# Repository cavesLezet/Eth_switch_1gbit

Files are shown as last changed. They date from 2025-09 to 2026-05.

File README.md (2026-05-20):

# Eth_switch_1gbit
на что смотрел:<br>
https://en.eeworld.com.cn/Reference_Designs/detail/76488<br>
https://lceda.cn/editor#id=103e28de87c54869b766a7df2fd9f07f<br>
https://github.com/Starrynightzyq/GE-Switch<br>
https://static.chipdip.ru/lib/518/DOC041518607.pdf<br>
https://oshwlab.com/hawaii0707/rtl8367rb-vb-cg<br>

инфа про светодиоды<br>
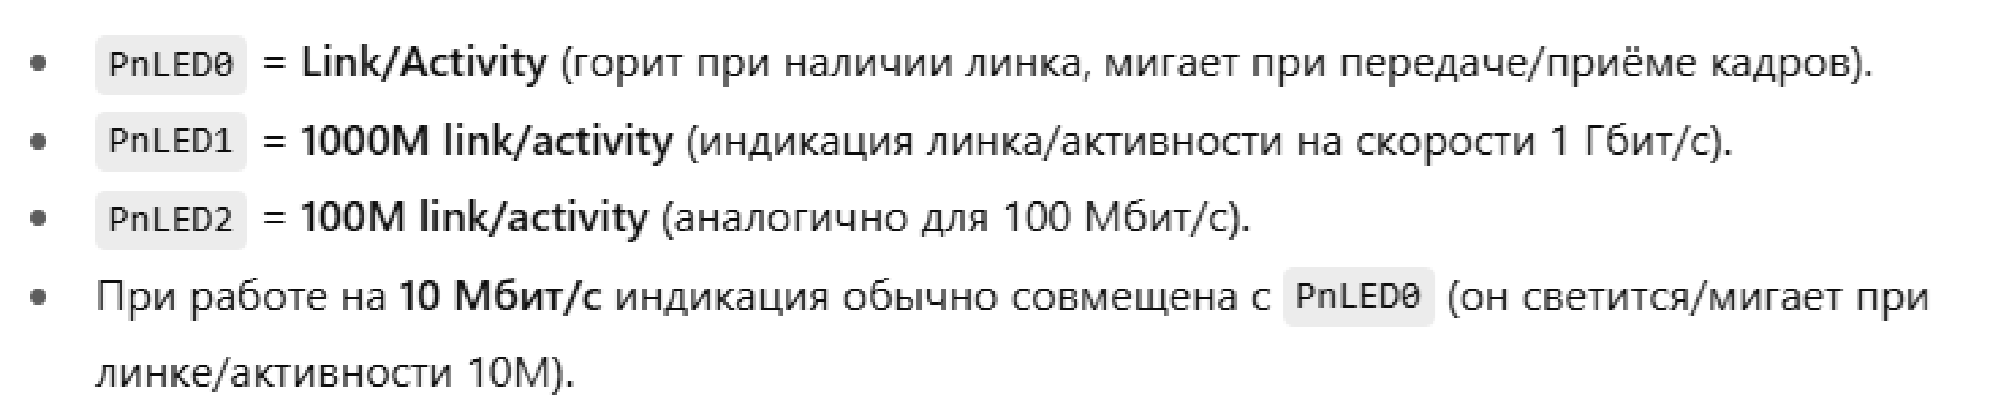
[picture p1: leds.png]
leds
<br>
[коммит с релизной докой](https://github.com/cavesLezet/Eth_switch_1gbit/commit/48998cd221b385a8897a50ce54fa7af490ef88a7)

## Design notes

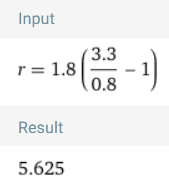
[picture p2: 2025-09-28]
Точечный рисунок (6).bmp

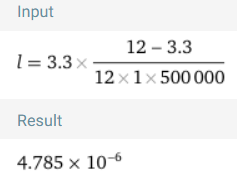
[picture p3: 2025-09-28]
Точечный рисунок (4).bmp

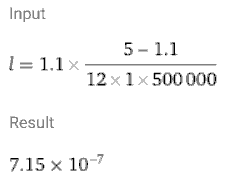
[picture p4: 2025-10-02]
Точечный рисунок (8).bmp

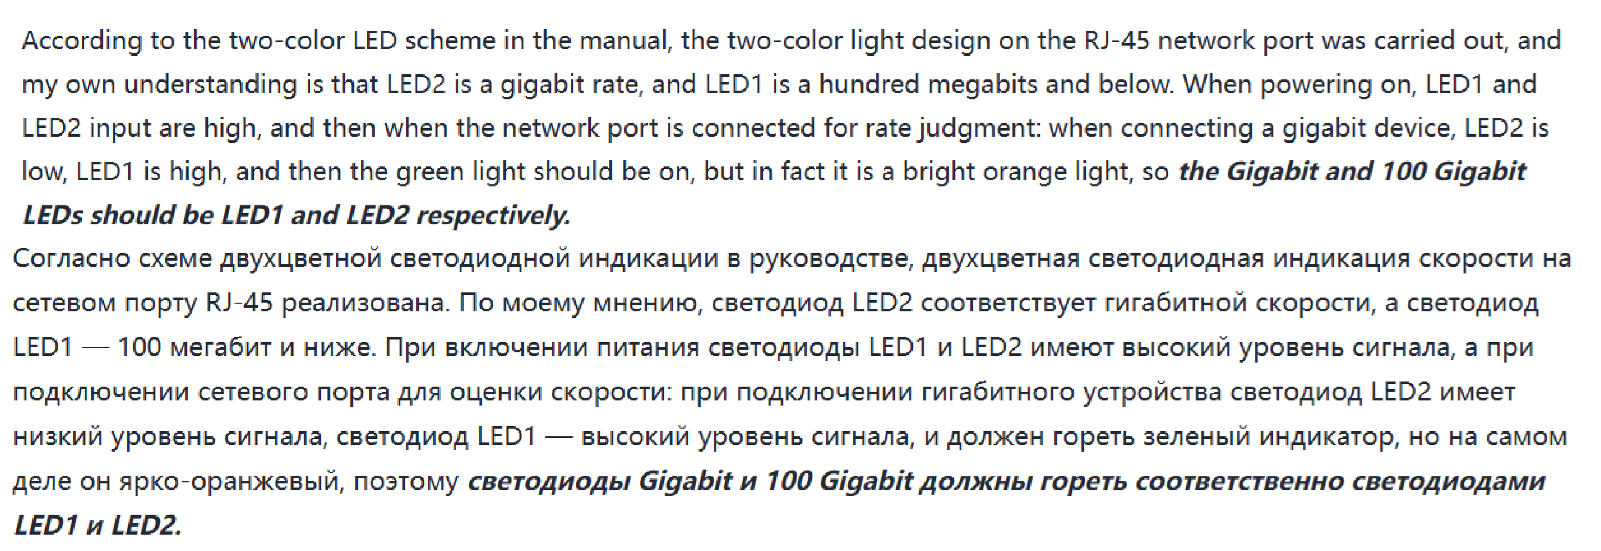
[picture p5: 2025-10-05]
hawaii0707.png

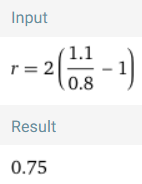
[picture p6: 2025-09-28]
Точечный рисунок (7).bmp

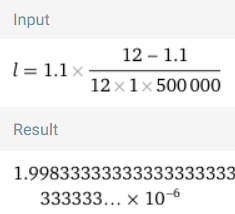
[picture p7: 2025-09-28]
Точечный рисунок (2).bmp

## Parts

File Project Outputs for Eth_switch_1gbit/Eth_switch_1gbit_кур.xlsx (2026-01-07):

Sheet: Eth_switch_1gbit_кур
Designator | Line # | Quantity |  |  | Footprint | Name | Description
C1...C19, C21, C22, C24, C27, C28 | 2 | 24 | 2 | 48 | 0402C | Capacitor | Конденсатор 0402C ёмкостью 0,1 мк 10%, 16 В, X7R
C20, C23 | 3 | 2 | 2 | 4 | 0603C | GRM1885C1H220J | Конденсатор 0603C ёмкостью 22п 5%, 50 В, NP0
C25, C32...C35, C39, C40 | 4 | 7 | 2 | 14 | 0603C | Capacitor | Конденсатор 0603C ёмкостью 0,1 мк 10%, 50 В, X7R
C26, C29, C30, C37, C38 | 5 | 5 | 2 | 10 | 1210C | Capacitor | Конденсатор 1210C ёмкостью 10 мк 10%, 35 В, X7R
C31 | 6 | 1 | 2 | 2 | 1210C | Capacitor | Конденсатор 1210C ёмкостью 1н 10%, 1000 В, X7R
C36 | 7 | 1 | 2 | 2 | ECAP_SMD_10,3x10,3 | Capacitor_polar | Конденсатор алюминиевый электролитический 470мкФ 16В ±20% (10х10)мм SMD 460мА 2000часов 105°C
C41, C42 | 8 | 2 | 2 | 4 | 0603C | Capacitor | Конденсатор 0603C ёмкостью 100 п 10%, 50 В, X7R
C43...C48 | 9 | 6 | 2 | 12 | 1210C | Capacitor | Конденсатор 1210C ёмкостью 22 мк 10%, 25 В, X7R
DA1, DA2 | 10 | 2 | 6 | 12 | TSOT26 | AP63200 | DC-DC понижающий преобразователь, Vin: 3.8 - 40 В, adj, 2 А
DD1 | 11 | 1 | 129 | 129 | LQFP128_14x14_exposed_pad | RTL8367RB-VB | Управляемый коммутатор второго уровня на 5+2 порта 10/100/1000M
L1 | 12 | 1 | 2 | 2 | CDRH6D12 | CDRH6D12NP-2R2NC | Индуктивность на 2,2 мкГн, номинальный ток 2,5 А
L2 | 13 | 1 | 2 | 2 | B82462G4 | B82472G6472M | Индуктивность на 4,7 мкГн, номинальный ток 2,5 А
R1 | 14 | 1 | 2 | 2 | 0603R | RC0603FR-072K49L | 0.1Вт 0603 2.49 кОм, 1%, Чип резистор
R2, R19...R30, R32...R34 | 15 | 16 | 2 | 32 | 0402R | Resistor | Резистор номиналом 4,7 кОм 1%
R3...R18 | 16 | 16 | 2 | 32 | 0402R | Resistor | Резистор номиналом 1,0 кОм 1%
R31 | 17 | 1 | 2 | 2 | 0603R | Resistor | Резистор номиналом 1,0 МОм 1%
R35...R42 | 18 | 8 | 2 | 16 | 0402R | Resistor | Резистор номиналом 470 Ом 1%
R43 | 19 | 1 | 2 | 2 | 0603R | Resistor | Резистор номиналом 10 кОм 1%
R44 | 20 | 1 | 2 | 2 | 0603R | Resistor | Резистор номиналом 750 Ом 1%
R45 | 21 | 1 | 2 | 2 | 0603R | Resistor | Резистор номиналом 2,0 кОм 1%
R46 | 22 | 1 | 2 | 2 | 0603R | Resistor | Резистор номиналом 5,6 кОм 1%
R47 | 23 | 1 | 2 | 2 | 0603R | Resistor | Резистор номиналом 1,8 кОм 1%
S1 | 24 | 1 | 4 | 4 | Button_SMD_6x6 | Tact_button | Тактовая кнопка
VD1 | 25 | 1 | 2 | 2 | SMA | SMAJ12A | Защитный диод на 12 В, рассеиваемая мощность 400 Вт
VD2 | 26 | 1 | 2 | 2 | mini_MELF_3.5mm | BZV55-B10 | Стабилитрон 10В, 2%, 0.5Вт
VT1 | 27 | 1 | 3 | 3 | SOT23-3 | AO3401A | P-канальный MOSFET
XP1 | 28 | 1 | 2 | 2 | MOLEX_MICRO-FIT_430450200 | 430450200 | Разъем типа провод-плата, угловой, 3 мм, 2 контакт(-ов), Штыревой Разъем, Серия Micro-Fit для монтажа в отверстия
XS1...XS4 | 29 | 4 | 18 | 72 | JK00136NL | JK0-0136NL | Модульный разъем (с трансформатором) Cat5/6, RJ45, Гнездо, 1 порт
ZQ1 | 30 | 1 | 4 | 4 | X322525MOB4SI | X322525MOB4SI | Кварцевый резонатор SMD 25 МГц ±10ppm SMD-3225_4P
 |  | 110 | 210

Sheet: Лист1
№ | Наименование | 1-ый вариант
 |  | Автоматическая
 |  | Оборудование | Tоп, сек
5 | Входной контроль печатной платы | TSMixed - тестер для входного контроля аналоговых, цифровых, аналого-цифровых ИС и систем в сборке | 150
10 | Трафаретное нанесение паяльной пасты | Автоматический конвейерный трафаретный принтер GT++ | 60
15 | Контроль качества нанесения паяльной пасты | 3D-инспекция качества нанесения паяльной пасты OMRON VP6000-V | 35
20 | Установка SMD компонентов | SMD установщик компонентов Tronstol E1 (standart) | 100
25 | Визуальный контроль | Цифровой микроскоп Tagarno Prestige Auto | 5
30 | Пайка оплавлением | Конвекционная печь конвейерного типа для оплавления припоя на печатных платах T12L | 200
35 | Визуальный контроль качества пайки | Система рентгеновского контроля СРК-1000 | 5
40 | Установка компонентов для монтажа в отверстия | Автомат для смешанного монтажа ПП с SMD-, ТНТ- и компонентами нестандартной формы JM-20 | 150
45 | Флюсование | Линия селективной пайки ZSW NPS-1 | 40
50 | Селективная пайка | Линия селективной пайки ZSW NPS-1 | 310
55 | Промывка и сушка печатной платы | Установка отмывки трафаретов и печатных плат УСОТП‑1 | 510
60 | Визуальный контроль | Цифровой микроскоп Tagarno Prestige Auto | 15
65 | Функциональный контроль | Функциональный и FLASH тестер XILS600 | 40
70 | Нанесение защитного покрытия | Установка селективного нанесения влагозащитных покрытий на печатные платы, SC-900 | 10
75 | Контроль качества нанесения защитного покрытия | 3D-Системы контроля качества нанесения защитного покрытия Parmi серия Sigmax | 20
 |  |  | 1650

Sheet: Лист2
№ | Наименование | Вариант №2 ручной метод производства
 |  | Оборудование | Tоп, сек
5 | Входной контроль печатной платы | 1)Установить ПП | 300
 |  | 2)Прверить ПП на отсутствие разрывов проводников, на замыкания, на дефекты переходных отверстий
 |  | 3)Извлечь печатную плату
10 | Трафаретное нанесение паяльной пасты | 1)Установить ПП на стол и зафиксировать | 210
 |  | 2)Установить трафарет поверх установленной ПП
 |  | 2)Нанести дозу паяльной пасты специальным шприцем таким образом чтоб сверху трафарета оказался валик из паяльной пасты
 |  | 3)Установить ракель под углом 45 градусов к поверхности трафарета
 |  | 4)Провести ракелем по трафарету прокатывая валик паяльной пасты сверху вниз
 |  | 5)Удалить остатки паяльной пасты
 |  | 6)Извлечь трафарет
 |  | 7)Извлечь ПП
15 | Контроль качества нанесения паяльной пасты | 1)Установить печатную плату | 120
 |  | 2)Сравнить отпечаток на плате с трафаретом.
 |  | 3) проверить наличие дефектов нанесения паяльной пасты (перемычки, размазывание и т.д.)
 |  | 3) Извлечь печатную плату
20 | Установка SMD компонентов | 1)Установить печатную плату и зафиксировать её в пространстве | 100
 |  | 2) подготовить требуемые SMD – компоненты и приборы для их установки на ПП
 |  | 3)Установить SMD – компоненты
 |  | 4)Извлечь печатную плату
25 | Визуальный контроль | 1)Установить печатную плату под микроскоп | 60
 |  | 2)Проверить правильность установки SMD-компонентов
 |  | 3)извлечь плату
30 | Пайка оплавлением | 1)Установить печатную плату в печь | 1000
 |  | 2)Выставить необходимы температурный профиль и временное ограничение
 |  | 3)извлечь печатную плату из печи
35 | Визуальный контроль качества пайки | 1)Установить печатную плату под микроскоп | 60
 |  | 2)Проверить правильность установки SMD-компонентов
 |  | 3)Извлечь плату
40 | Установка компонентов для монтажа в отверстия | 1)Установить печатную плату | 150
 |  | 2)Установить компоненты на плату
 |  | 3)Извлечь плату
45 | Флюсование | 1)Установить печатную плату обратной стороной | 120
 |  | 2)Смочить флюсом ЛТИ-120 все выводы компонентов, монтируемых в отверстия
50 | Пайка паяльником | 1)Припаять все компоненты | 1500
 |  | 2)Извлечь плату
55 | Промывка и сушка печатной платы | 1)Установить ПП в ультразвуковую ванну со спиртобензиновой смесью | 500
 |  | 2)Запустить ванну на 5 минут
 |  | 3) Извлечь печатную плату
 |  | 3)Сдуть компрессором спирт с платы
60 | Визуальный контроль | 1)Установить печатную плату под микроскоп | 150
 |  | 2)Проверить правильность установки КМО
 |  | 3)Просмотреть все точки паяных соединений
 |  | 4)Извлечь плату
65 | Функциональный контроль | 1)Подать питание на печатную плату | 300
 |  | 2)Подключить к 2 компьютерам через разъемы 8p8c
 |  | 3)Проверить наличие и скорость связи
 |  | 4)Снять питание с платы
70 | Нанесение защитного покрытия | 1)Установить печатный узел и зафиксировать его | 240
 |  | 2)Нанести лак кисточкой везде где необходимо
 |  | 3)Высушить
75 | Контроль качества нанесения защитного покрытия | 1)Установить печатную плату | 20
 |  | 2)Просмотреть места с защитным покрытием
 |  | 3)Извлечь плату
 |  |  | 4830

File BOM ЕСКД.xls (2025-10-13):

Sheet: Главный
Разработал: | Field=DrawnBy | Тип печатной платы необходим для добавления номера документа печатной платы в спецификаию:
Проверил: | Field=CheckedBy | 1 - сборочная единица
Норм. контроль: |  | 2 - деталь
Утвердил: | Field=ApprovedBy
Литера: |  | Параметр GroupSpecification служит для помещения компонента в один из разделов:
Децимальный нормер: | Field=Decimal_Number_Shematic | 1 - Сборочные единицы
Наименование проекта: | Field=Title1 | 2 - Детали
 | Field=Title2 | 3 - Стандартные изделия
Организация: | Гидравлика | 4 - Прочие изделия (раздел по умолчанию)
Дец. номер документа печатной платы: | Field=Decimal_Number_PCB | Если компонент не относится к разделу "Прочие изделия" то в параметре Rem указывается наименование позции, а в параметре
Тип печ. платы (сборка/деталь): | 2 | DocNumber - децимальный номер чертежа
 |  |  | валуе | толерансе | повер/вольтаге
Column=Designator | Column=Rem | Column=Footprint | Column= | Column= | Column= | Column=Description | Column=PartNumber | Column=Manufacturer | Column=Quantity | Column=Примечание | Column=GroupSpecification | Column=DocNumber
1 | 2 | 3 | 4 | 5 | 6 | 7 | 8 | 9 | 10 | 11 | 12 | 13

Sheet: Компоненты
Поз. обозначение | Наименование ед.ч. | Наименование мн.ч.
A | Устройство | Устройства
BAT | Элемент питания | Элементы питания
BF | Телефон | Телефоны
BH | Датчик Холла | Датчики Холла
BM | Микрофон | Микрофоны
C | Конденсатор | Конденсаторы
D | Микросхема | Микросхемы
DA | Микросхема | Микросхемы
DD | Микросхема | Микросхемы
FU | Предохранитель | Предохранители
F | Разрядник | Разрядники
GB | Батарея | Батареи
G | Генератор | Генераторы
H | Устройство индикации | Устройства индикации
HG | Устройство индикации | Устройства индикации
HL | Устройство индикации | Устройства индикации
K | Реле | Реле
KV | Реле | Реле
L | Катушка индуктивности | Катушки индуктивности
R | Резистор | Резисторы
RK | Терморезистор | Терморезисторы
RP | Потенциометр | Потенциометры
RU | Варистор | Варисторы
S | Переключатель | Переключатели
SA | Переключатель | Переключатели
SB | Переключатель | Переключатели
T | Трансформатор | Трансформаторы
VD | Диод | Диоды
VS | Тиристор | Тиристоры
VT | Транзистор | Транзисторы
WA | Антенна | Антенны
X | Соединитель | Соединители
XP | Соединитель | Соединители
XS | Соединитель | Соединители
XW | Соединитель | Соединители
Z | Кварцевый резонатор | Кварцевые резонаторы
ZQ | Кварцевый резонатор | Кварцевые резонаторы
FP | Термопредохранитель | Термопредохранители
U | Оптопара | Оптопары

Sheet: Сп 1
Перв. примен. | Формат | Зона | Поз. | Обозначение | Наименование | Кол. | Примечание
Справ. №
Подп. и дата
Инв. № дубл.
Взам. инв. №
Подп. и дата
Инв. № подл.

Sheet: Сп 2
 | Формат | Зона | Поз. | Обозначение | Наименование | Кол. | Примечание
Подп. и дата
Инв. № дубл.
Взам. инв. №
Подп. и дата
Инв. № подл.

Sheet: Лист 1
Перв. примен. | Поз. обозна-чение | Наименование | Кол. | Примечание
Справ. №
Подп. и дата
Инв. № дубл.
Взам. инв. №
Подп. и дата
Инв. № подл.

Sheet: Лист 2
 | Поз. обозна-чение | Наименование | Кол. | Примечание
Подп. и дата
Инв. № дубл.
Взам. инв. №
Подп. и дата
Инв. № подл.

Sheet: Рег. Изм.
 | ЛИСТ РЕГИСТРАЦИИ ИЗМЕНЕНИЙ
 | Изм. | Номера листов (страниц) |  |  |  | Всего листов (страниц) в докум. | № докум. | Входящий № сопроводитель- ного докум. и дата | Подпись | Дата
 |  | изменен- ных | заменен- ных | новых | аннули- рованных
Подп. и дата
Инв. № дубл.
Взам. инв. №
Подп. и дата
Инв. № подл.

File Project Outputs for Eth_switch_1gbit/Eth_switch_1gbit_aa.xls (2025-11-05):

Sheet: SP 1
Перв. примен. | Формат | Зона | Поз. | Обозначение | Наименование | Кол. | Примечание
 |  |  |  |  | Документация
 |  |  |  | ГИДР.123456.012 СБ | Сборочный чертеж
 |  |  |  | ГИДР.123456.012 Э3 | Схема электрическая
 |  |  |  |  | принципиальная
 | А4 |  |  | ГИДР.123456.012 ПЭ3 | Перечень элементов
Справ. №
 |  |  |  |  | Детали
 |  |  | 1 | ГИДР.123456.013 | Плата печатная | 1
 |  |  |  |  | Прочие изделия
 |  |  |  |  | Конденсаторы
 |  |  | 2 |  | Конденсатор 0402C ёмкостью 0,1 мк | 1 | C1...C19,
 |  |  |  |  | 10%, 16 В, X7R 0402C |  | C21, C22,
 |  |  |  |  |  |  | C24, C27,
 |  |  |  |  |  |  | C28
Подп. и дата |  |  | 3 |  | Конденсатор 0603C ёмкостью 22п 5%, | 1 | C20, C23
 |  |  |  |  | 50 В, NP0 0603C
 |  |  | 4 |  | Конденсатор 0603C ёмкостью 0,1 мк | 1 | C25,
 |  |  |  |  | 10%, 50 В, X7R 0603C |  | C32...C35
Инв. № дубл. |  |  | 5 |  | Конденсатор 1210C | 2 | C26, C29,
 |  |  |  |  |  |  | C30, C37,
 |  |  |  |  |  |  | C38,
Взам. инв. № |  |  |  |  |  |  | C43...C48
 |  |  | 6 |  | Конденсатор 1210C ёмкостью 1н 10%, | 1 | C31
 |  |  |  |  | 1000 В, X7R 1210C
 |  |  | 7 |  | Конденсатор алюминиевый | 1 | C36
Подп. и дата
Инв. № подл.

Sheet: SP 2
 | Формат | Зона | Поз. | Обозначение | Наименование | Кол. | Примечание
 |  |  |  |  | электролитический 470мкФ 16В ±20%
 |  |  |  |  | (10х10)мм SMD 460мА 2000часов 105°C
 |  |  |  |  | ECAP_SMD_10,3x10,3
 |  |  | 8 |  | Конденсатор 0603C | 2 | C39, C40,
 |  |  |  |  |  |  | C41, C42
 |  |  |  |  | Микросхемы
 |  |  | 9 |  | DC-DC понижающий преобразователь, | 1 | DA1, DA2
 |  |  |  |  | Vin: 3.8 - 40 В, adj, 2 А TSOT26
 |  |  | 10 |  | Управляемый коммутатор второго | 1 | DD1
 |  |  |  |  | уровня на 5+2 порта 10/100/1000M
 |  |  |  |  | LQFP128_14x14_exposed_pad
 |  |  |  |  | Катушки индуктивности
 |  |  | 11 |  | Индуктивность на 2,2 мкГн, | 1 | L1
 |  |  |  |  | номинальный ток 2,5 А CDRH6D12
 |  |  | 12 |  | Индуктивность на 4,7 мкГн, | 1 | L2
Подп. и дата |  |  |  |  | номинальный ток 2,5 А B82462G4
 |  |  |  |  | Резисторы
 |  |  | 13 |  | 0.1Вт 0603 2.49 кОм, 1%, Чип | 1 | R1
Инв. № дубл. |  |  |  |  | резистор 0603R
 |  |  | 14 |  | Резистор номиналом 4,7 кОм 1% 0402R | 1 | R2,
 |  |  |  |  |  |  | R19...R30,
Взам. инв. № |  |  |  |  |  |  | R32...R34
 |  |  | 15 |  | Резистор номиналом 1,0 кОм 1% 0402R | 1 | R3...R18
Подп. и дата |  |  | 16 |  | Резистор номиналом 1,0 МОм 1% 0603R | 1 | R31
 |  |  | 17 |  | Резистор номиналом 470 Ом 1% 0402R | 1 | R35...R42
 |  |  | 18 |  | Резистор номиналом 10 кОм 1% 0603R | 1 | R43
Инв. № подл.

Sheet: SP 3
 | Формат | Зона | Поз. | Обозначение | Наименование | Кол. | Примечание
 |  |  | 19 |  | Резистор номиналом 750 Ом 1% 0603R | 1 | R44
 |  |  | 20 |  | Резистор номиналом 2,0 кОм 1% 0603R | 1 | R45
 |  |  | 21 |  | Резистор номиналом 5,6 кОм 1% 0603R | 1 | R46
 |  |  | 22 |  | Резистор номиналом 1,8 кОм 1% 0603R | 1 | R47
 |  |  |  |  | Переключатели
 |  |  | 23 |  | Тактовая кнопка Button_SMD_6x6 | 1 | S1
 |  |  | 24 |  | Solder bridge, мост припоя, | 1 | SB1, SB2
 |  |  |  |  | запаиваемая перемычка, net tie,
 |  |  |  |  | jumper 0805SB
 |  |  |  |  | Диоды
 |  |  | 25 |  | Защитный диод на 12 В, рассеиваемая | 1 | VD1
 |  |  |  |  | мощность 400 Вт SMA
Подп. и дата |  |  | 26 |  | Стабилитрон 10В, 2%, 0.5Вт | 1 | VD2
 |  |  |  |  | mini_MELF_3.5mm
 |  |  | 27 |  | Транзистор P-канальный MOSFET | 1 | VT1
Инв. № дубл. |  |  |  |  | SOT23-3
 |  |  |  |  | Соединители
Взам. инв. № |  |  | 28 |  | Разъем типа провод-плата, угловой, | 1 | XP1
 |  |  |  |  | 3 мм, 2 контакт(-ов), Штыревой
 |  |  |  |  | Разъем, Серия Micro-Fit для монтажа
Подп. и дата |  |  |  |  | в отверстия
 |  |  |  |  | MOLEX_MICRO-FIT_430450200
 |  |  | 29 |  | Модульный разъем (с | 1 | XS1...XS4
 |  |  |  |  | трансформатором) Cat5/6, RJ45,
Инв. № подл. |  |  |  |  | Гнездо, 1 порт JK00136NL

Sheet: SP 4
 | Формат | Зона | Поз. | Обозначение | Наименование | Кол. | Примечание
 |  |  | 30 |  | Кварцевый резонатор Кварцевый | 1 | ZQ1
 |  |  |  |  | резонатор SMD 25 МГц ±10ppm
 |  |  |  |  | SMD-3225_4P X322525MOB4SI
Подп. и дата
Инв. № дубл.
Взам. инв. №
Подп. и дата
Инв. № подл.

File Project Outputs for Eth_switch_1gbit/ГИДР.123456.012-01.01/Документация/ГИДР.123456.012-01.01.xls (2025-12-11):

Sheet: SP 1
Перв. примен. | Формат | Зона | Поз. | Обозначение | Наименование | Кол. | Примечание
 |  |  |  |  | Документация
 |  |  |  | ГИДР.123456.012 СБ | Сборочный чертеж
 |  |  |  | ГИДР.123456.012 Э3 | Схема электрическая
 |  |  |  |  | принципиальная
 | А4 |  |  | ГИДР.123456.012 ПЭ3 | Перечень элементов
Справ. №
 |  |  |  |  | Детали
 |  |  | 1 | ГИДР.123456.013 | Плата печатная | 1
 |  |  |  |  | Прочие изделия
 |  |  |  |  | Конденсаторы
 |  |  | 2 |  | Конденсатор 0402C ёмкостью 0,1 мк | 1 | C1...C19,
 |  |  |  |  | 10%, 16 В, X7R 0402C |  | C21, C22,
 |  |  |  |  |  |  | C24, C27,
 |  |  |  |  |  |  | C28
Подп. и дата |  |  | 3 |  | Конденсатор 0603C ёмкостью 22п 5%, | 1 | C20, C23
 |  |  |  |  | 50 В, NP0 0603C
 |  |  | 4 |  | Конденсатор 0603C ёмкостью 0,1 мк | 1 | C25,
 |  |  |  |  | 10%, 50 В, X7R 0603C |  | C32...C35,
Инв. № дубл. |  |  |  |  |  |  | C39, C40
 |  |  | 5 |  | Конденсатор 1210C ёмкостью 10 мк | 1 | C26, C29,
 |  |  |  |  | 10%, 35 В, X7R 1210C |  | C30, C37,
Взам. инв. № |  |  |  |  |  |  | C38
 |  |  | 6 |  | Конденсатор 1210C ёмкостью 1н 10%, | 1 | C31
 |  |  |  |  | 1000 В, X7R 1210C
 |  |  | 7 |  | Конденсатор алюминиевый | 1 | C36
Подп. и дата
Инв. № подл.

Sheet: SP 2
 | Формат | Зона | Поз. | Обозначение | Наименование | Кол. | Примечание
 |  |  |  |  | электролитический 470мкФ 16В ±20%
 |  |  |  |  | (10х10)мм SMD 460мА 2000часов 105°C
 |  |  |  |  | ECAP_SMD_10,3x10,3
 |  |  | 8 |  | Конденсатор 0603C ёмкостью 100 п | 1 | C41, C42
 |  |  |  |  | 10%, 50 В, X7R 0603C
 |  |  | 9 |  | Конденсатор 1210C ёмкостью 22 мк | 1 | C43...C48
 |  |  |  |  | 10%, 25 В, X7R 1210C
 |  |  |  |  | Микросхемы
 |  |  | 10 |  | DC-DC понижающий преобразователь, | 1 | DA1, DA2
 |  |  |  |  | Vin: 3.8 - 40 В, adj, 2 А TSOT26
 |  |  | 11 |  | Управляемый коммутатор второго | 1 | DD1
 |  |  |  |  | уровня на 5+2 порта 10/100/1000M
 |  |  |  |  | LQFP128_14x14_exposed_pad
 |  |  |  |  | Катушки индуктивности
 |  |  | 12 |  | Индуктивность на 2,2 мкГн, | 1 | L1
Подп. и дата |  |  |  |  | номинальный ток 2,5 А CDRH6D12
 |  |  | 13 |  | Индуктивность на 4,7 мкГн, | 1 | L2
 |  |  |  |  | номинальный ток 2,5 А B82462G4
Инв. № дубл. |  |  |  |  | Резисторы
 |  |  | 14 |  | 0.1Вт 0603 2.49 кОм, 1%, Чип | 1 | R1
 |  |  |  |  | резистор 0603R
Взам. инв. № |  |  | 15 |  | Резистор номиналом 4,7 кОм 1% 0402R | 1 | R2,
 |  |  |  |  |  |  | R19...R30,
 |  |  |  |  |  |  | R32...R34
Подп. и дата |  |  | 16 |  | Резистор номиналом 1,0 кОм 1% 0402R | 1 | R3...R18
 |  |  | 17 |  | Резистор номиналом 1,0 МОм 1% 0603R | 1 | R31
Инв. № подл.

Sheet: SP 3
 | Формат | Зона | Поз. | Обозначение | Наименование | Кол. | Примечание
 |  |  | 18 |  | Резистор номиналом 470 Ом 1% 0402R | 1 | R35...R42
 |  |  | 19 |  | Резистор номиналом 10 кОм 1% 0603R | 1 | R43
 |  |  | 20 |  | Резистор номиналом 750 Ом 1% 0603R | 1 | R44
 |  |  | 21 |  | Резистор номиналом 2,0 кОм 1% 0603R | 1 | R45
 |  |  | 22 |  | Резистор номиналом 5,6 кОм 1% 0603R | 1 | R46
 |  |  | 23 |  | Резистор номиналом 1,8 кОм 1% 0603R | 1 | R47
 |  |  | 24 |  | Переключатель Тактовая кнопка | 1 | S1
 |  |  |  |  | Button_SMD_6x6
 |  |  |  |  | Диоды
 |  |  | 25 |  | Защитный диод на 12 В, рассеиваемая | 1 | VD1
 |  |  |  |  | мощность 400 Вт SMA
 |  |  | 26 |  | Стабилитрон 10В, 2%, 0.5Вт | 1 | VD2
Подп. и дата |  |  |  |  | mini_MELF_3.5mm
 |  |  | 27 |  | Транзистор P-канальный MOSFET | 1 | VT1
 |  |  |  |  | SOT23-3
Инв. № дубл.
 |  |  |  |  | Соединители
 |  |  | 28 |  | Разъем типа провод-плата, угловой, | 1 | XP1
Взам. инв. № |  |  |  |  | 3 мм, 2 контакт(-ов), Штыревой
 |  |  |  |  | Разъем, Серия Micro-Fit для монтажа
 |  |  |  |  | в отверстия
Подп. и дата |  |  |  |  | MOLEX_MICRO-FIT_430450200
 |  |  | 29 |  | Модульный разъем (с | 1 | XS1...XS4
 |  |  |  |  | трансформатором) Cat5/6, RJ45,
 |  |  |  |  | Гнездо, 1 порт JK00136NL
Инв. № подл.

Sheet: SP 4
 | Формат | Зона | Поз. | Обозначение | Наименование | Кол. | Примечание
 |  |  | 30 |  | Кварцевый резонатор Кварцевый | 1 | ZQ1
 |  |  |  |  | резонатор SMD 25 МГц ±10ppm
 |  |  |  |  | SMD-3225_4P X322525MOB4SI
Подп. и дата
Инв. № дубл.
Взам. инв. №
Подп. и дата
Инв. № подл.

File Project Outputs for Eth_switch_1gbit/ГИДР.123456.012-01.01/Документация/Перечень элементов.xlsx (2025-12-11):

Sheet: PER 1
Перв. примен. | Поз. обозна-чение | Наименование | Кол. | Примечание
 |  | Конденсаторы
 | C1...C19, C21, C22, C24, C27, C28 | Конденсатор 0402C ёмкостью 0,1 мк 10%, 16 В, X7R 0402C | 1
 | C20, C23 | Конденсатор 0603C ёмкостью 22п 5%, 50 В, NP0 0603C | 1
 | C25, C32...C35, C39, C40 | Конденсатор 0603C ёмкостью 0,1 мк 10%, 50 В, X7R 0603C | 1
 | C26, C29, C30, C37, C38 | Конденсатор 1210C ёмкостью 10 мк 10%, 35 В, X7R 1210C | 1
Справ. № | C31 | Конденсатор 1210C ёмкостью 1н 10%, 1000 В, X7R 1210C | 1
 | C36 | Конденсатор алюминиевый электролитический 470мкФ 16В ±20% | 1
 |  | (10х10)мм SMD 460мА 2000часов 105°C ECAP_SMD_10,3x10,3
 | C41, C42 | Конденсатор 0603C ёмкостью 100 п 10%, 50 В, X7R 0603C | 1
 | C43...C48 | Конденсатор 1210C ёмкостью 22 мк 10%, 25 В, X7R 1210C | 1
 |  | Микросхемы
 | DA1, DA2 | DC-DC понижающий преобразователь, Vin: 3.8 - 40 В, adj, 2 А | 1
 |  | TSOT26
 | DD1 | Управляемый коммутатор второго уровня на 5+2 порта | 1
Подп. и дата |  | 10/100/1000M LQFP128_14x14_exposed_pad
 |  | Катушки индуктивности
 | L1 | Индуктивность на 2,2 мкГн, номинальный ток 2,5 А CDRH6D12 | 1
Инв. № дубл. | L2 | Индуктивность на 4,7 мкГн, номинальный ток 2,5 А B82462G4 | 1
 |  | Резисторы
Взам. инв. № | R1 | 0.1Вт 0603 2.49 кОм, 1%, Чип резистор 0603R | 1
 | R2, R19...R30, R32...R34 | Резистор номиналом 4,7 кОм 1% 0402R | 1
 | R3...R18 | Резистор номиналом 1,0 кОм 1% 0402R | 1
 | R31 | Резистор номиналом 1,0 МОм 1% 0603R | 1
Подп. и дата
Инв. № подл.

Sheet: PER 2
 | Поз. обозна-чение | Наименование | Кол. | Примечание
 | R35...R42 | Резистор номиналом 470 Ом 1% 0402R | 1
 | R43 | Резистор номиналом 10 кОм 1% 0603R | 1
 | R44 | Резистор номиналом 750 Ом 1% 0603R | 1
 | R45 | Резистор номиналом 2,0 кОм 1% 0603R | 1
 | R46 | Резистор номиналом 5,6 кОм 1% 0603R | 1
 | R47 | Резистор номиналом 1,8 кОм 1% 0603R | 1
 | S1 | Переключатель Тактовая кнопка Button_SMD_6x6 | 1
 |  | Диоды
 | VD1 | Защитный диод на 12 В, рассеиваемая мощность 400 Вт SMA | 1
 | VD2 | Стабилитрон 10В, 2%, 0.5Вт mini_MELF_3.5mm | 1
 | VT1 | Транзистор P-канальный MOSFET SOT23-3 | 1
 |  | Соединители
 | XP1 | Разъем типа провод-плата, угловой, 3 мм, 2 контакт(-ов), | 1
Подп. и дата |  | Штыревой Разъем, Серия Micro-Fit для монтажа в отверстия
 |  | MOLEX_MICRO-FIT_430450200
 | XS1...XS4 | Модульный разъем (с трансформатором) Cat5/6, RJ45, Гнездо, | 1
 |  | 1 порт JK00136NL
Инв. № дубл.
 | ZQ1 | Кварцевый резонатор Кварцевый резонатор SMD 25 МГц ±10ppm | 1
 |  | SMD-3225_4P X322525MOB4SI
Взам. инв. №
Подп. и дата
Инв. № подл.

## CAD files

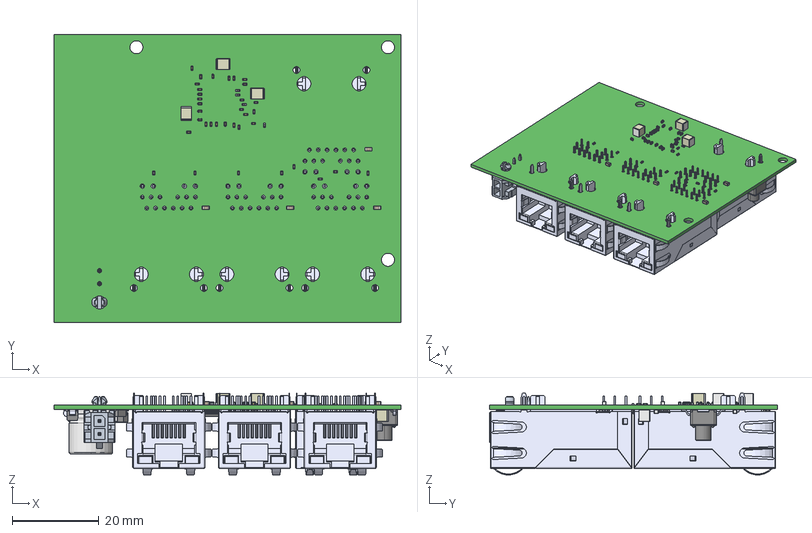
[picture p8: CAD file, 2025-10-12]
eth_witch.step
80.0 x 66.5 x 18.8 mm
TL3301FF160QG--3DModel-STEP-418109
Cap_Murata_GRM32ER60J107ME20L_eec x 36
Pins x 2
Extruded x 2
JK0-0136NL x 4
SOT-23
term1 x 40
term2 x 40
LQFP128_EPAD_RTK

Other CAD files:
Project Outputs for Eth_switch_1gbit/ГИДР.123456.012-01.01/Mechanical models/eth_witch.DWG
Project Outputs for Eth_switch_1gbit/ГИДР.123456.012-01.01/Mechanical models/eth_witch(01).step
Project Outputs for Eth_switch_1gbit/ГИДР.123456.012-01.01/Mechanical models/eth_witch(01).x_t

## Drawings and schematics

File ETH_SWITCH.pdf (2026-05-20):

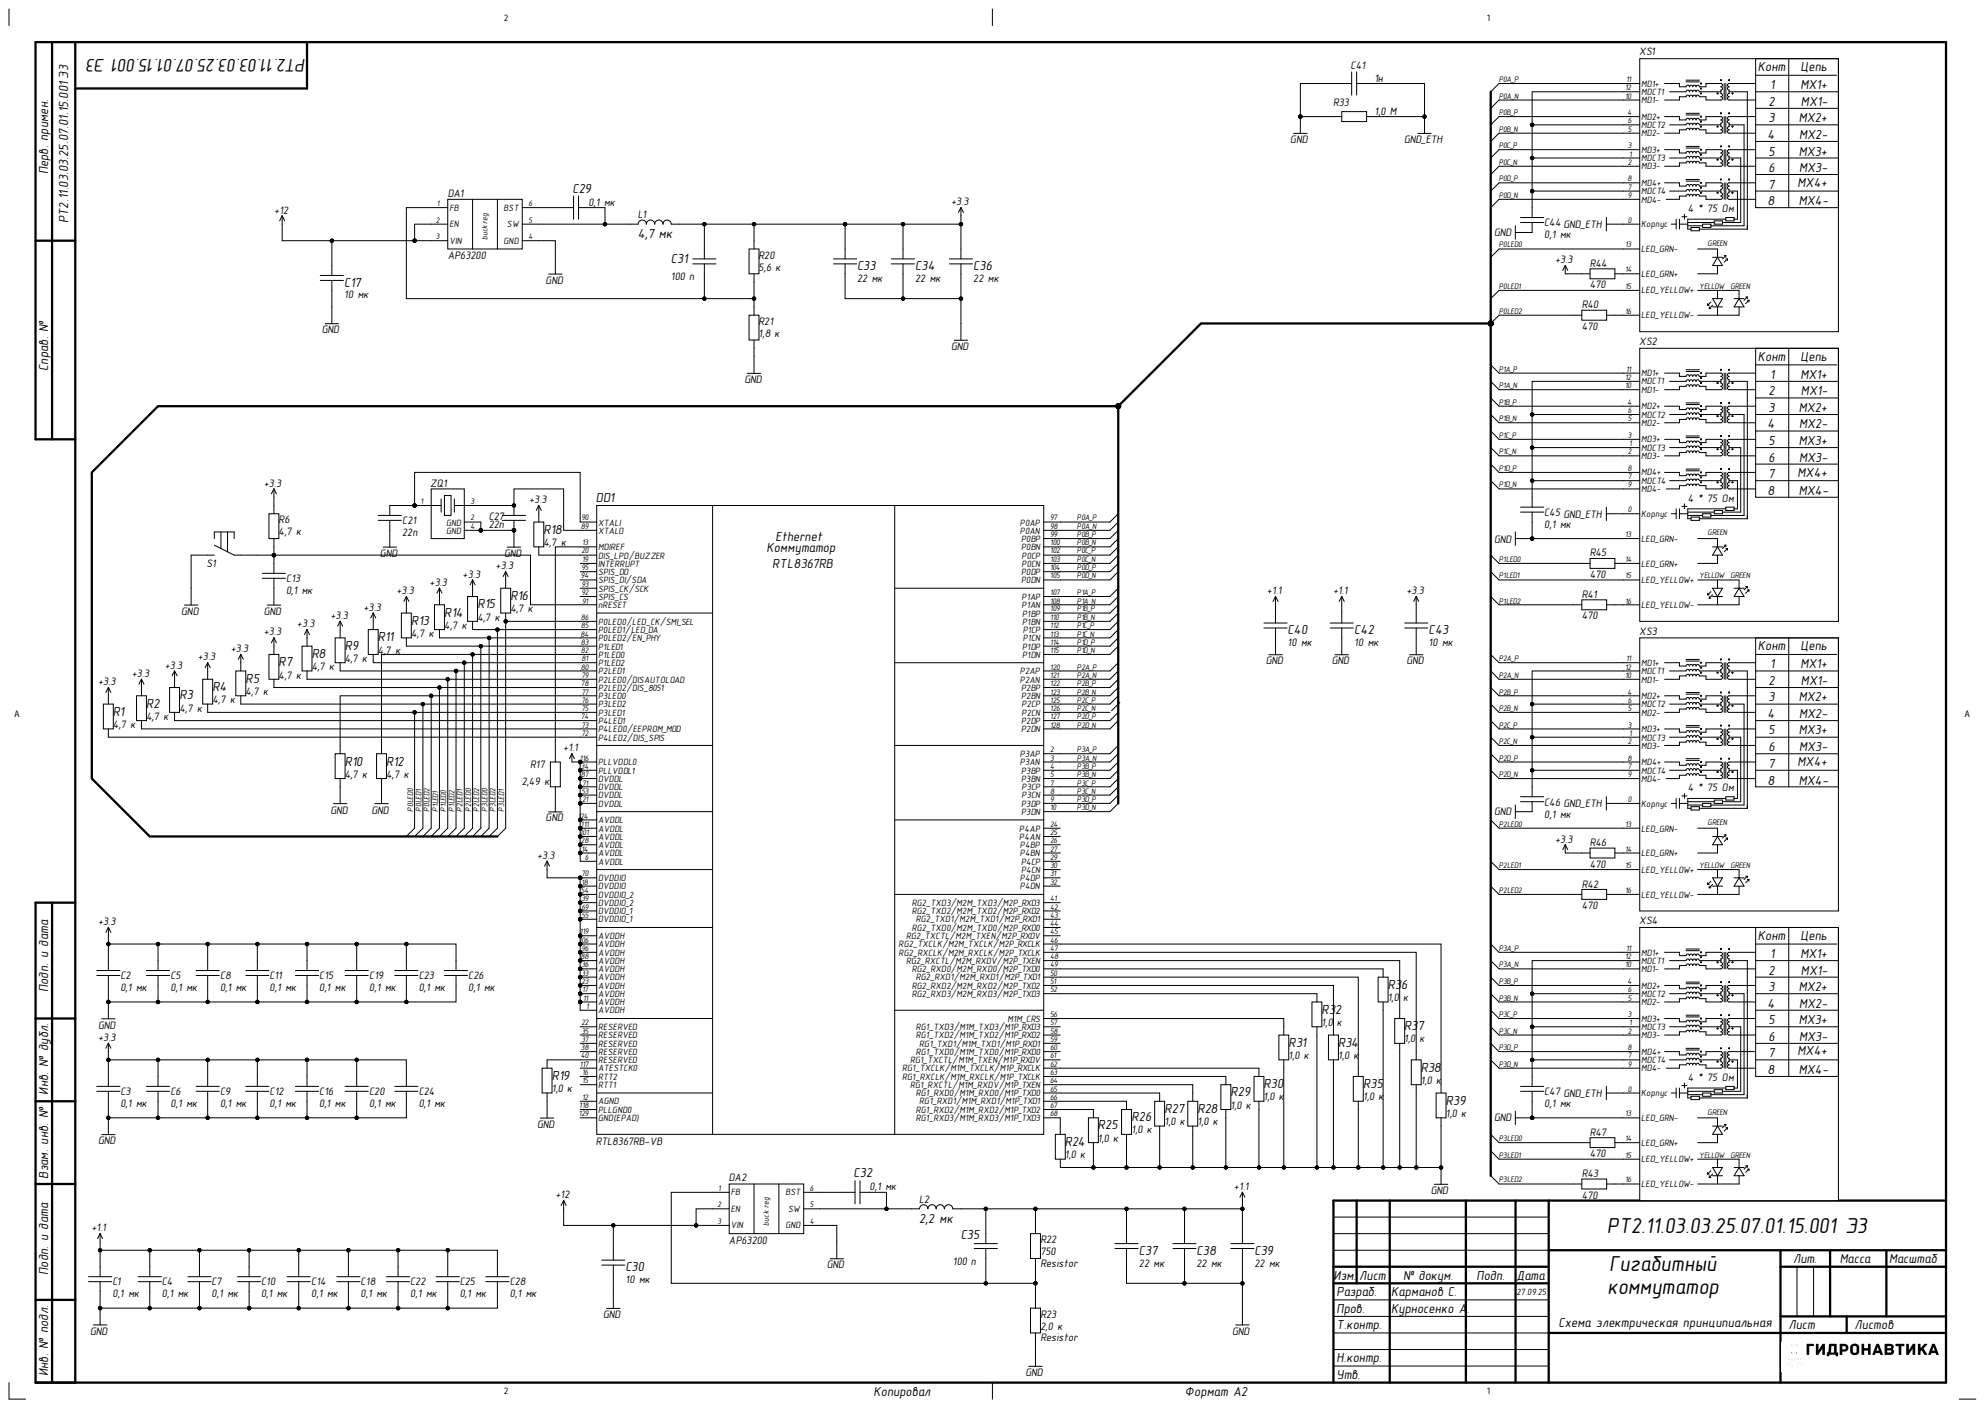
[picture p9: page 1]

Конт | Цепь
1 | MX1+

Инв. № подл. Инв. № дубл. Подп. и дата Взам. инв. № Подп. и дата Перв. примен. Справ. №

MD1- 10 MD2+ 4 MDCT2 6 | | 2 | MX1-

MD2- 5 MD3+ 3 MDCT3 1 | | 4 | MX2-

MD3- 2 MD4+ 8 MDCT4 7 | | 6 | MX3-

MD4- 9 Корпус 0 | | 8

+3.3 +3.3 +3.3 +3.3 C13 | INTERRUPT 19 DIS_LPD/BUZZER 20

MD1- 10 MD2+ 4 MDCT2 6 | 2 | MX1-

MD2- 5 MD3+ 3 MDCT3 1 | 4 | MX2-

Гигабитный коммутатор Схема электрическая принципиальная | Лит. | Масса | Масштаб

Изм. | Лист | № докум. | Подп. | Дата
Разраб. | | Карманов С. | | 27.09.25
Пров. | | Курносенко А.
Т.контр. | | | | | Лист | Листов

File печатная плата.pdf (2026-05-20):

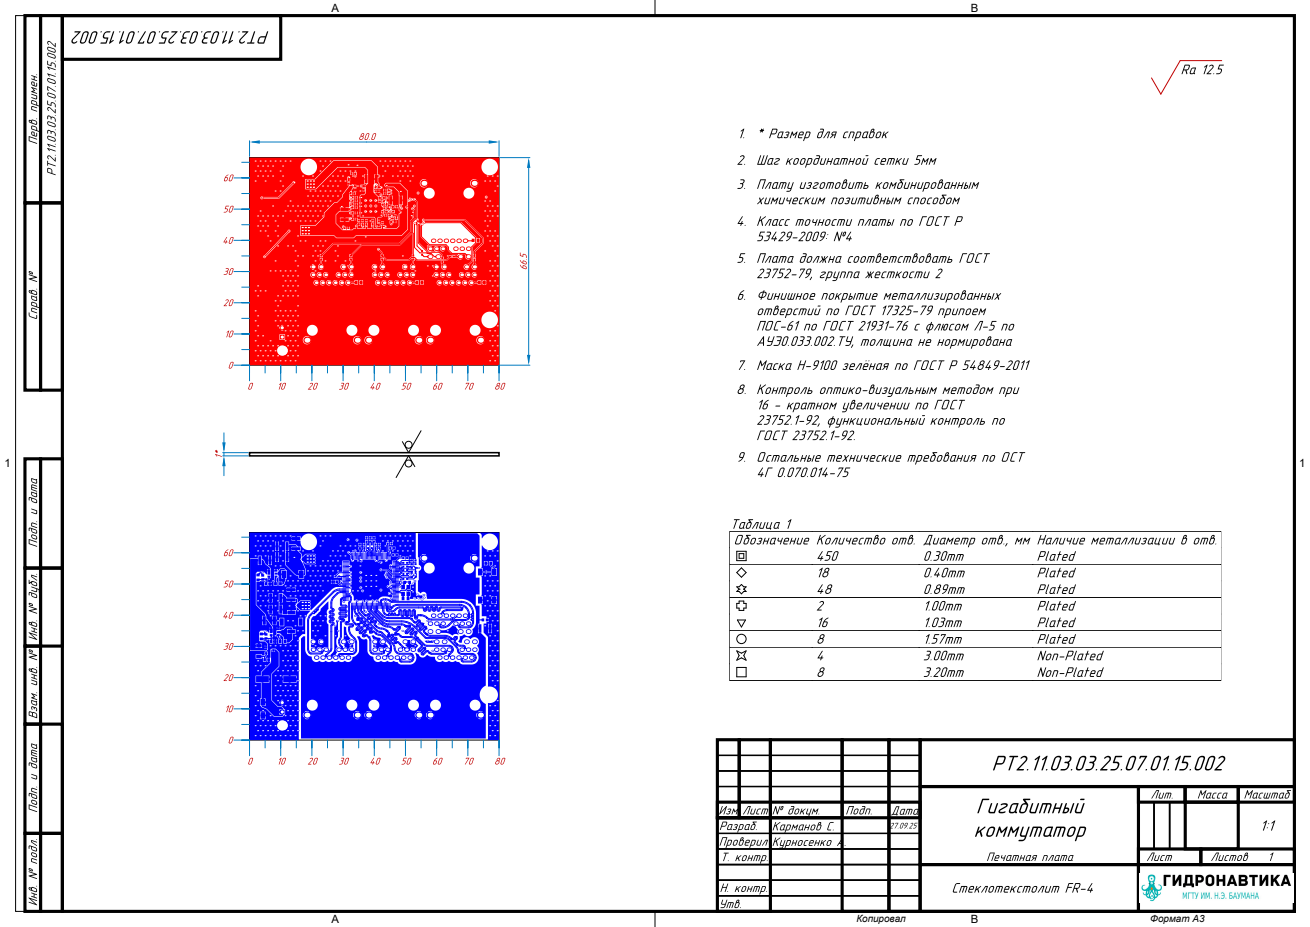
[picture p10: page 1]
Копировал; Формат А3

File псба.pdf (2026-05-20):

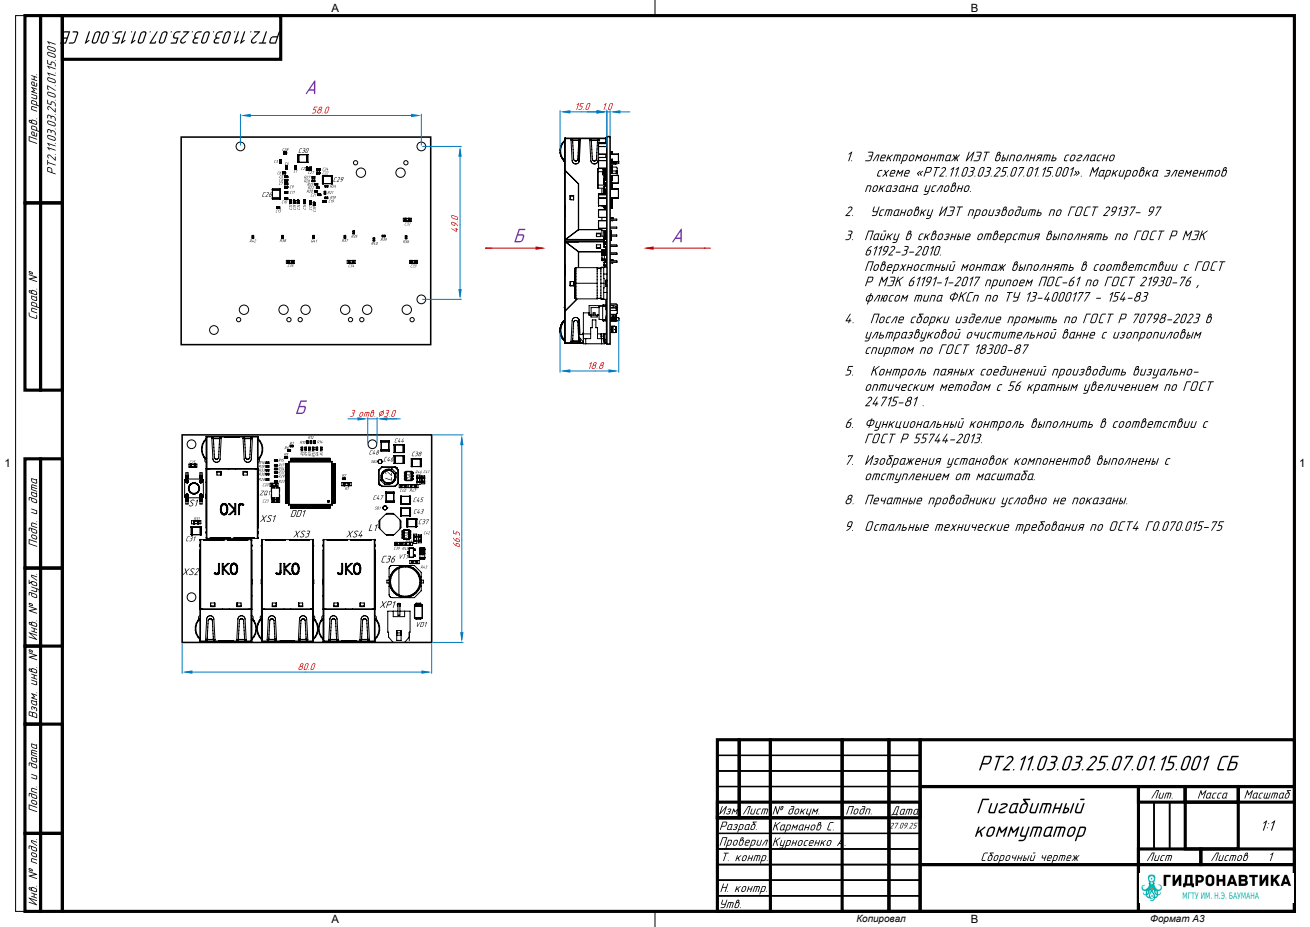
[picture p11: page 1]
Копировал; Формат А3

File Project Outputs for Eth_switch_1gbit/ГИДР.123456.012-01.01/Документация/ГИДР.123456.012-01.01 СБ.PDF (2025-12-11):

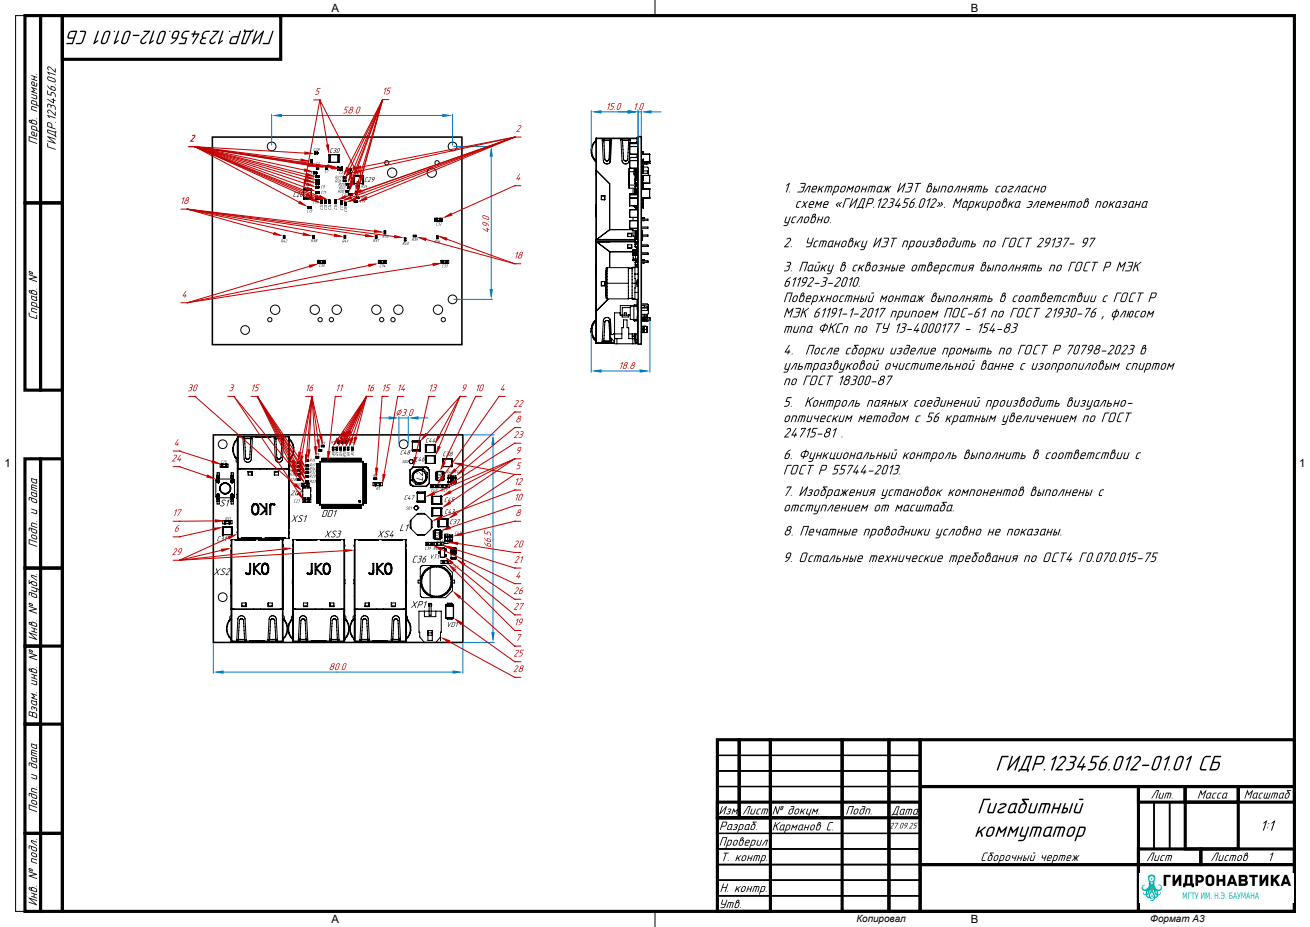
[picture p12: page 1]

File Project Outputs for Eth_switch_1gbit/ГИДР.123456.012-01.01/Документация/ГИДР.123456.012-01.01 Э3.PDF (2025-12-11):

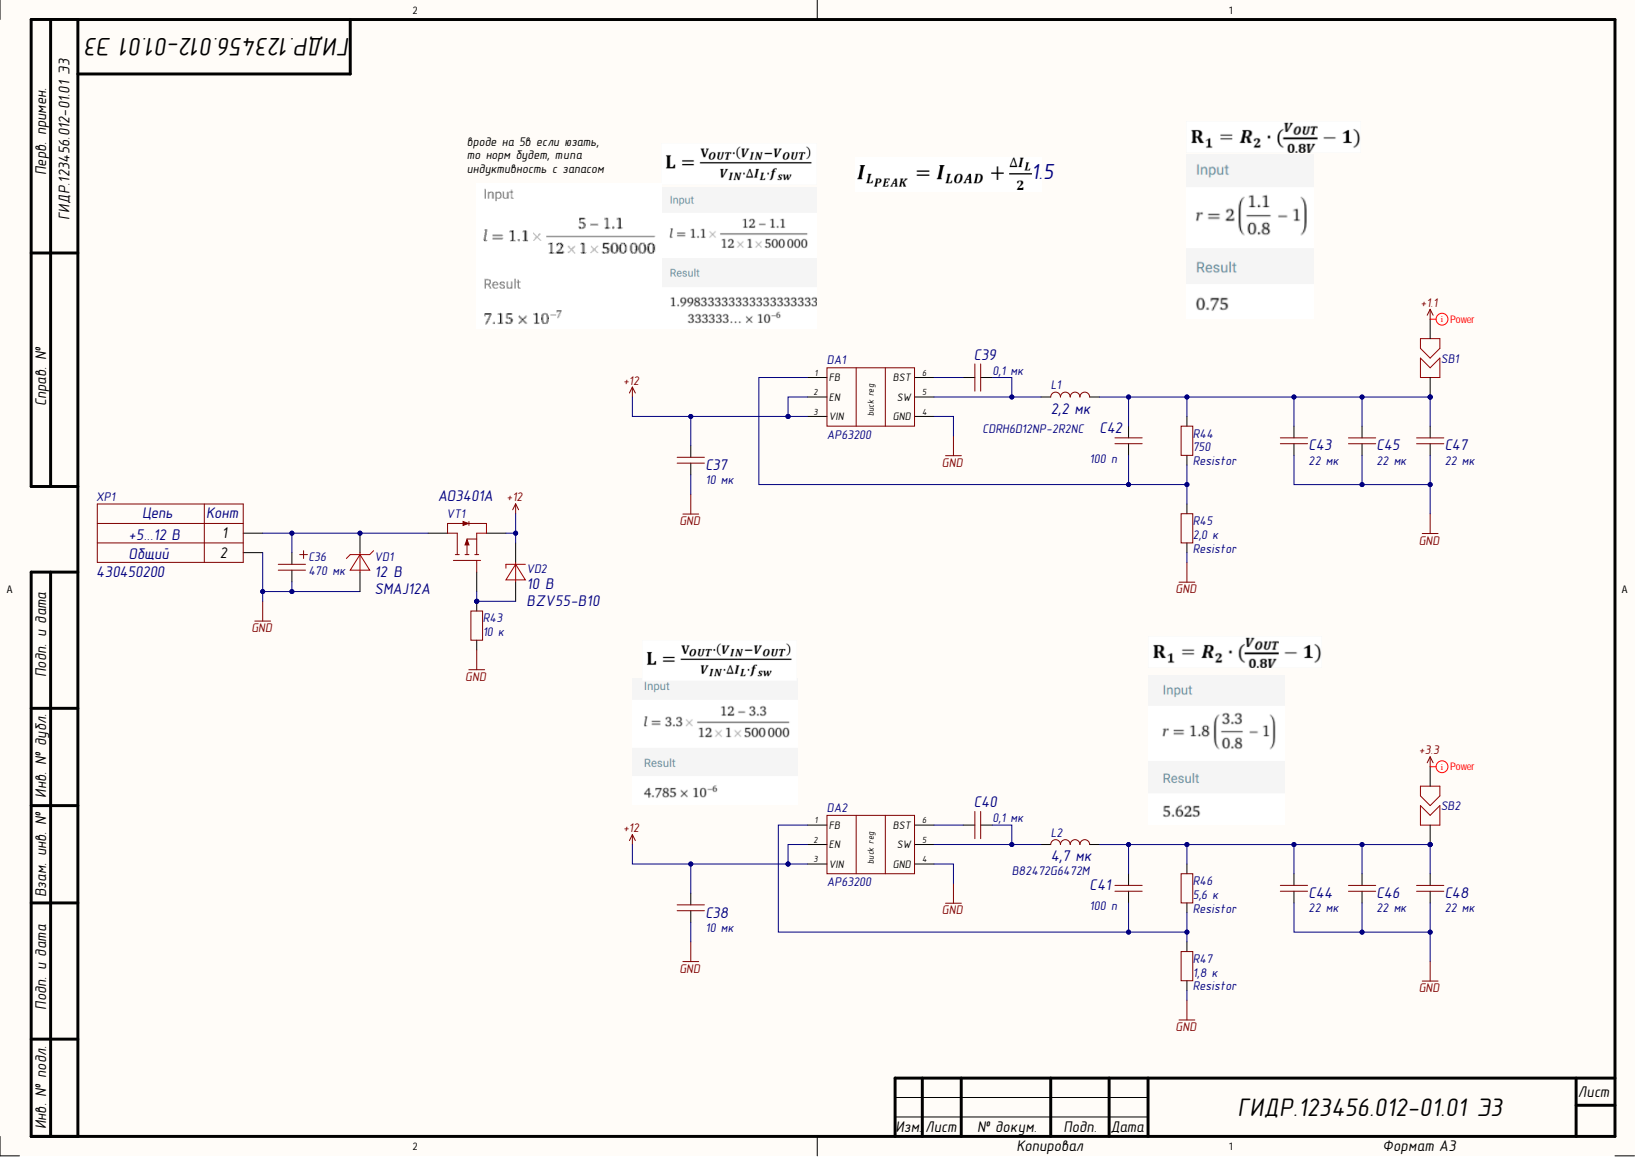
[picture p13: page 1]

Инв. № подл. Инв. № дубл. Подп. и дата Взам. инв. № Подп. и дата Перв. примен. Справ. №

вроде на
то норм будет, типа
индуктивность

Цепь | Конт
Общий +5...12 В | 12

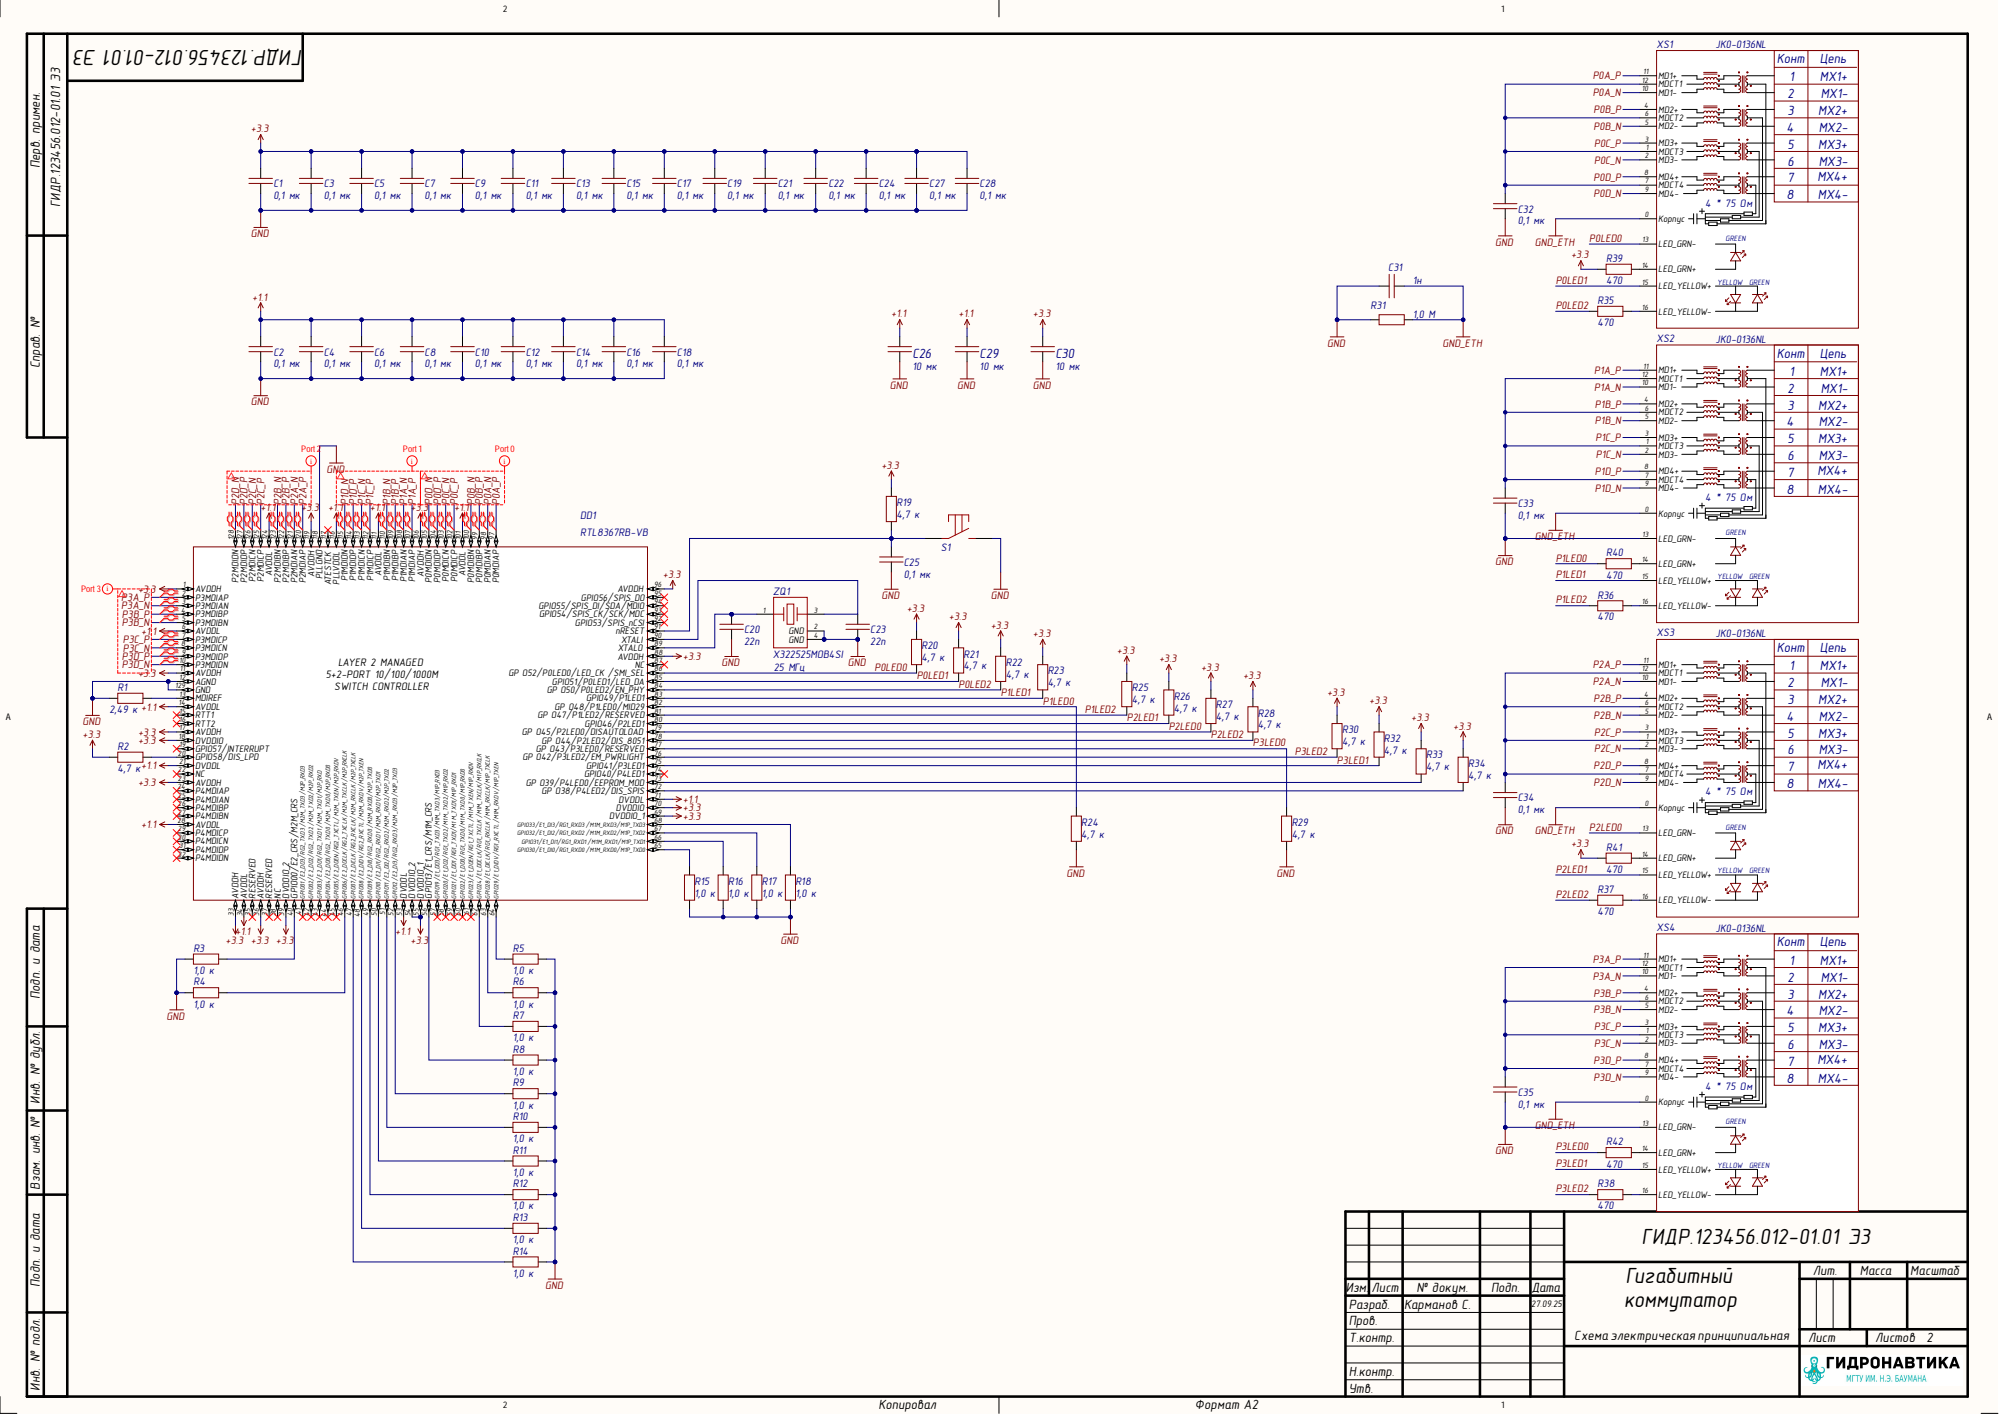
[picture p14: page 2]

Конт | Цепь
1 | MX1+

M2M_CRS 40 DVDDIO_2 39 NC 38 RESERVED 37 AVDDH 36 RESERVED 35 AVDDL 34 AVDDH 33

ГИДР.123456.012-01.01 Э3

Гигабитный коммутатор Схема электрическая принципиальная | Лит. | Масса | Масштаб

Разраб. | Карманов С. | 27.09.25
Пров.
Т.контр. | | | Лист | Листов 2

Н.контр.
Утв.

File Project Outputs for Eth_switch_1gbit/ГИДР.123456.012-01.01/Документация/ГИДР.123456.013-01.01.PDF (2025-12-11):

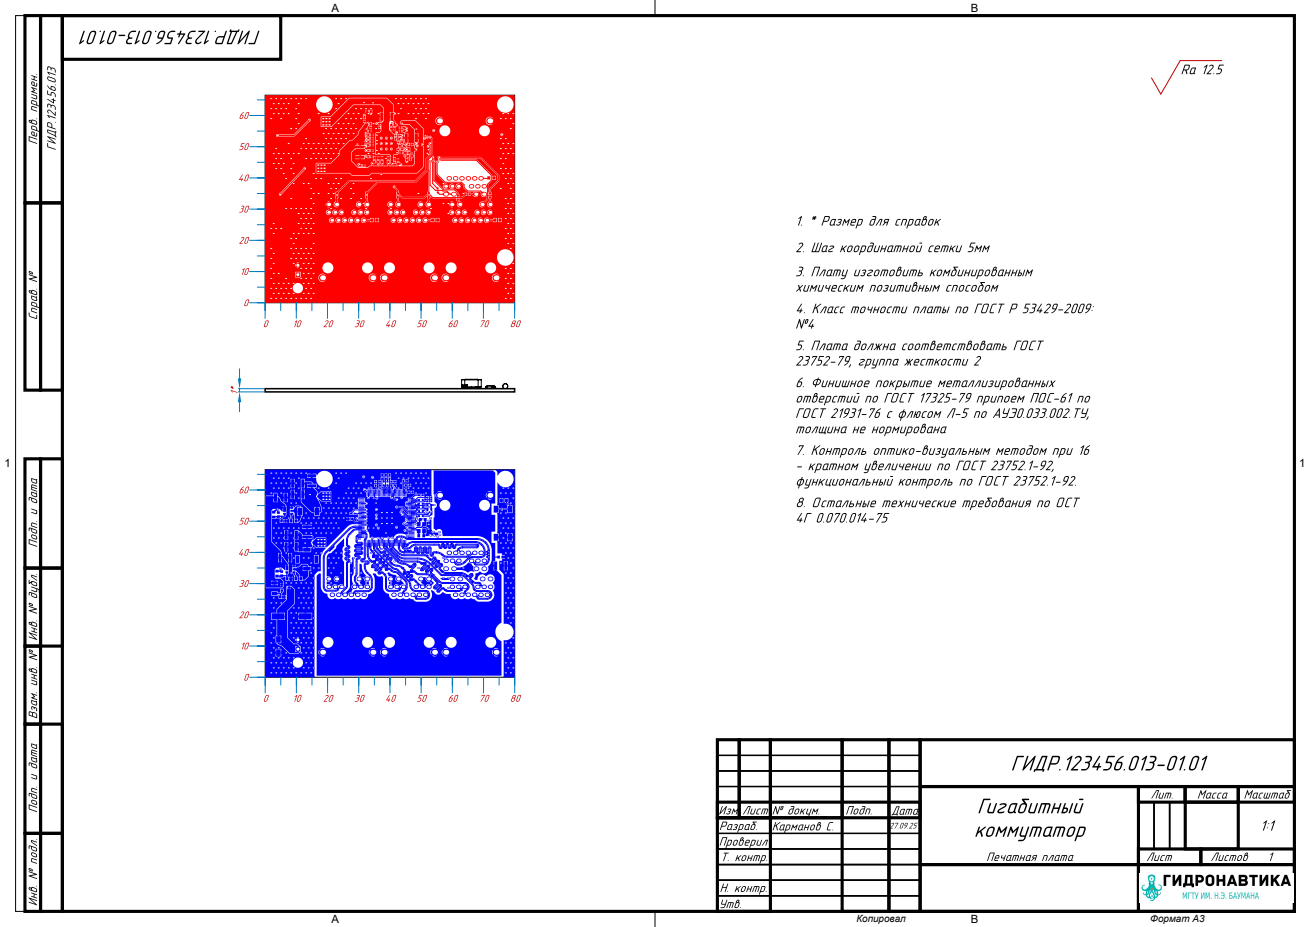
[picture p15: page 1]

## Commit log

2025-09-28 сделал схему дцдц, добавил основные компоненты
    [ETH_SWITCH.SchDoc, Eth_switch_1gbit.PrjPcb, dc-dc.SchDoc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]
2025-09-29 кварц, подключил разъемы, землю их, прикинул размеры платы
    [ETH_SWITCH.SchDoc, eth_witch.PcbDoc]
2025-10-01 разобрался со светодиодами и страппинг пинамиgit add . это было не просто
    [ETH_SWITCH.SchDoc, Eth_switch_1gbit.PrjPcb, eth_witch.step]
2025-10-02 закончил схему
    [ETH_SWITCH.SchDoc, Eth_switch_1gbit.PrjPcb, dc-dc.SchDoc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]
2025-10-03 ридми
2025-10-05 поменял разъемчик питания, начал трассировку
    [ETH_SWITCH.SchDoc, Eth_switch_1gbit.PrjPcb, dc-dc.SchDoc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]
2025-10-12 доразвёл, начал кд делать
    [ETH_SWITCH.SchDoc, Eth_switch_1gbit.PrjPcb, Eth_switch_1gbit.xls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]
2025-10-12 добавил чертеж пп
2025-10-12 для редизера
    [ETH_SWITCH.SchDoc, Eth_switch_1gbit.PrjPcb, Eth_switch_1gbit.xls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]
2025-10-13 доки
    [BOM ЕСКД.xls, Eth_switch_1gbit.PrjPcb, Eth_switch_1gbit.xls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]
2025-10-13 технологические правки
    [eth_witch.PcbDoc]
2025-10-13 попытка исправить сп и пэ
    [BOM ЕСКД.xls]
2025-10-13 с исправленным макросом
    [BOM ЕСКД.xls, Eth_switch_1gbit.xls, ГИДР.123456.012-01.01 ПЭ3.xls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]
2025-10-13 добавил картиночки на шелкуху
    [eth_witch.PcbDoc]
2025-10-13 для релизера
2025-10-13 доки, вроде конечная версия
    [BOM ЕСКД.xls, eth_witch(01).step, eth_witch(01).x_t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]
2025-10-14 последние
    [eth_witch.PcbDoc]
2025-10-14 ну все сча точно заказываем
    [eth_witch(01).step, eth_witch(01).x_t, eth_witch.DWG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]
2025-11-05 добавил спеку и перечень
    [Eth_switch_1gbit_aa.xls, ГИДР.123456.012-01.01 ПЭ.xlsx, ГИДР.123456.012-01.01.xls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]
2025-12-11 правки кд для курсача
    [ETH_SWITCH.SchDoc, Eth_switch_1gbit.PrjPcb, dc-dc.SchDoc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]
2025-12-11 релиз
    [ETH_SWITCH.SchDoc, Eth_switch_1gbit.PrjPcb, dc-dc.SchDoc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]
2026-01-07 какое то говно для курсача
    [Eth_switch_1gbit.PrjPcb, Eth_switch_1gbit_кур.xlsx, eth_witch.PcbDoc]
2026-05-20 это я для курсача по ескд доку делал
    [ETH_SWITCH.SchDoc, Eth_switch_1gbit.PrjPcb, eth_witch.PcbDoc]
